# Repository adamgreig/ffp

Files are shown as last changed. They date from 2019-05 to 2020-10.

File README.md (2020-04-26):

# FFP: Flash/FPGA Programmer

FFP is a dead-simple USB to bidirectional SPI bridge for programming iCE40
FPGAs and SPI flashes. The hardware is an STM32F042 and not much else.
Firmware and host software is written in Rust.

The firmware additionally supports SWD via the CMSIS-DAP v1 and v2 protocols,
so many debuggers such as [probe-rs], [OpenOCD], and [pyOCD] are able to
use an FFP to debug and program Cortex-M and other microcontrollers.

[probe-rs]: https://probe.rs
[OpenOCD]: http://openocd.org
[pyOCD]: https://github.com/mbedmicro/pyOCD

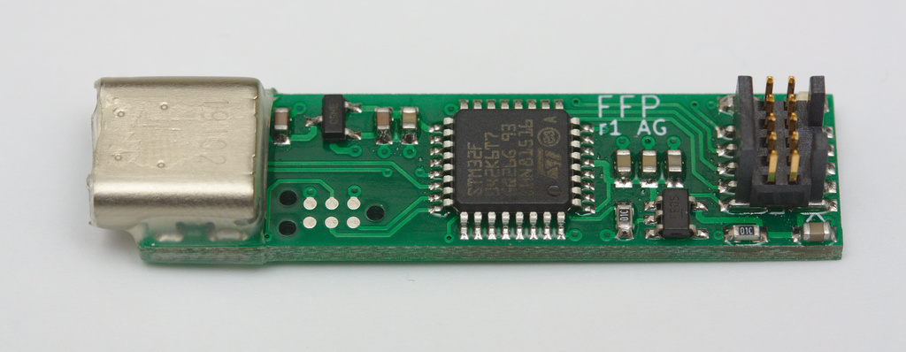
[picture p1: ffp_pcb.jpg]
Photo of FFP PCB


See [software/](software/) for the host-side software, [firmware/](firmware/)
for the embedded device firmware, and [hardware/](hardware/ffp/) for the
hardware design files.

## Pinout

The FFP r1 hardware uses a 5x2 pin 0.05"-pitch connector, which is also
commonly used for Cortex family microcontrollers for SWD and JTAG. The pinout
is deliberately compatible (though note `RESET` is moved) to allow hardware
reuse and for compatibility with tools such as TagConnect cables.

```ascii
          ______
    3v3 --|1  2|-- FLASH DI / FPGA DO / SWDIO
    GND --|3  4|-- CLK / SWCLK
    GND --|5  6|-- CS / SWO
        x-|7  8|-- FPGA nRST
    GND --|9 10|-- FLASH DO / FPGA DI / nRESET
          ------

```

This is the same pinout used by
[amp_flashprog](https://github.com/adamgreig/amp_flashprog), a custom firmware
for [Black Magic Probes](https://github.com/blacksphere/blackmagic) to bitbang
SPI to the same ends.

## Licence

Software and firmware is licensed under either of

* Apache License, Version 2.0 ([LICENSE-APACHE](LICENSE-APACHE) or
  http://www.apache.org/licenses/LICENSE-2.0)
* MIT license ([LICENSE-MIT](LICENSE-MIT) or http://opensource.org/licenses/MIT)

at your option.

Hardware design files are licensed under the Creative Commons Attribution
license ([CC-BY](https://creativecommons.org/licenses/by/4.0/)).

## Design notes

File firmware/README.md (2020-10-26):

# FFP Firmware

## Pre-built Binaries

Pre-built binaries are available for each release on the [Releases] page. See
below for instructions on using the files to program an FFP device. The easiest
method is to use `dfu-util` with the `ffp_firmware.dfu` pre-built file, which
uses the onboard USB bootloader.

[Releases]: https://github.com/adamgreig/ffp/releases

## Build Requirements

* You must have a working Rust compiler installed. Visit
[rustup.rs](https://rustup.rs) to install Rust.

* Your Rust toolchain needs the `thumbv6m-none-eabi` target installed:

```
rustup target add thumbv6m-none-eabi
```

## Building

Once Rust is installed, use Cargo to build:

```
cargo build --release
```

The resulting binary is an ELF file in
`target/thumbv6m-none-eabi/release/ffp_firmware` which can be programmed via
your usual programmer, or see below for generating a raw binary file and
bootloading over USB.

## Bootloading

You can reprogram the FFP using its built-in USB bootloader. You can use
[dfu-util](http://dfu-util.sourceforge.net/) or
[STM32CubeProg](https://www.st.com/en/development-tools/stm32cubeprog.html)
to perform the bootloading, both of which are available for Linux, MacOS, and
Windows.

To generate a binary file suitable for bootloading with dfu-util:
```
cargo build --release
arm-none-eabi-objcopy -O binary -S target/thumbv6m-none-eabi/release/ffp_firmware ffp.bin
dfu-suffix -a ffp.bin -v 0483 -p df11
```

STM32CubeProg can load data directly from the ELF file, but only if it has a
`.elf` extension. Simply copy the elf file:

```
cargo build --release
cp target/thumbv6m-none-eabi/release/ffp_firmware ffp_firmware.elf
```

To put an already-programmed FFP device into bootload mode:
```
ffp bootload
# or (if you do not have the ffp softare installed)
dfu-util -e
```
Devices which have a totally erased flash will come up in bootloader mode
automatically.

To bootload using dfu-util:
```
dfu-util -a 0 -s 0x08000000 -D ffp.bin
```

To bootload using STM32CubeProg, open the `ffp_firmware.elf` file made above,
and download it to the FFP.

Reconnect the device after programming to load new firmware.

### Preparing a DfuSe file

Using `dfu-tool`, a DfuSe file can be created for more convenient bootloading:

```
arm-none-eabi-objcopy -O binary -S target/thumbv6m-none-eabi/release/ffp_firmware ffp.bin
dfu-tool convert dfuse ffp.bin ffp.dfu
dfu-tool set-vendor ffp.dfu 0483
dfu-tool set-product ffp.dfu df11
dfu-tool set-address ffp.dfu 0x08000000
```

Unfortunately dfu-tool seemingly cannot set the alt setting to 0, only to >=1,
so that must still be specified by dfu-util:

```
dfu-util -a 0 -D ffp.dfu
```

## Licence

Licensed under either of

* Apache License, Version 2.0 ([LICENSE-APACHE](../LICENSE-APACHE)
  or http://www.apache.org/licenses/LICENSE-2.0 )
* MIT license ([LICENSE-MIT](../LICENSE-MIT) or
  http://opensource.org/licenses/MIT )

at your option.

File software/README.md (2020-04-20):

# FFP Control Software

The control software for FFP runs on your computer and uses the FFP hardware to
program an FPGA or SPI flash. It is written in Rust.

## Pre-built Binaries

Pre-built binaries are available for Windows and Linux on the [Releases] page.
You must have [libusb] installed or available on your system.

[Releases]: https://github.com/adamgreig/ffp/releases
[libusb]: https://libusb.info

## Build Requirements

* You must have a working Rust compiler installed. Visit
[rustup.rs](https://rustup.rs) to install Rust.

* You'll need to set up drivers or permissions to access the USB device, see
  the [drivers page](/driver/) for more details.

## Building

```
cargo build --release
```

You can either run the ffp executable directly from `target/release/ffp`, or
install it for your user using `cargo install --path .`.

## Installing

FFP software can be installed directly using Cargo:

```
cargo install ffp
```

## Usage

Run `ffp help` for detailed usage. Commonly used commands:

* `ffp fpga program bitstream.bin`
* `ffp fpga reset`
* `ffp fpga power on`
* `ffp flash id`
* `ffp flash program bitstream.bin`

## Python Alternative

The prototype for this software was written as a Python script which is also
available ([prog.py](/scripts/prog.py)).

## Cross-Compiling for Windows from Linux

From a stock Ubuntu 18.04 image, the following commands generate an `ffp.exe`
suitable for 64-bit Windows:

```sh
$ curl --proto '=https' --tlsv1.2 -sSf https://sh.rustup.rs | sh
# (accept defaults)
$ source $HOME/.cargo/env
$ cd /tmp
$ rustup target add x86_64-pc-windows-gnu
$ apt install -y p7zip-full build-essential gcc-mingw-w64-x86-64 libusb-1.0 pkg-config
$ wget https://github.com/libusb/libusb/releases/download/v1.0.23/libusb-1.0.23.7z
$ 7z x libusb-1.0.23.7z
$ git clone https://github.com/adamgreig/ffp
$ cd ffp/software
$ mkdir .cargo
$ echo -e '[target.x86_64-pc-windows-gnu]\nlinker = "x86_64-w64-mingw32-gcc"\nrustflags = [ "-L", "/tmp/MinGW64/dll/"]' > .cargo/config
$ env PKG_CONFIG_ALLOW_CROSS=1 cargo build --release --target x86_64-pc-windows-gnu
```

The resulting binary is `target/x86_64-pc-windows-gnu/release/ffp.exe`. It
needs the `libusb-1.0.dll` file from `/tmp/MinGW64/dll/` available on the
Windows system, either in the same directory as `ffp.exe` or installed
system-wide.

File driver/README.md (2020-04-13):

# FFP Platform-Specific Drivers

## Linux

Copy the `99-ffp.rules` file to your udev configuration directory and restart
udev:

```
sudo cp 99-ffp.rules /etc/udev/rules.d
sudo udevadm control --reload
```

Confirm you are in the `plugdev` group, or modify `99-ffp.rules` to use another
group or specify a specific user. If you have just added yourself to the
`plugdev` group (e.g., `sudo usermod -aG plugdev $USER`), you will need to
log out and log back in again for the group change to take effect.

## Windows

For use as an CMSIS-DAP v1 programmer, no additional driver installation should
be necessary, as the default HID drivers should work. However, this has not
been tested -- please report back if you've got the CMSIS-DAP functionality
working under Windows.

On Windows 8 and above, WinUSB drivers should automatically be installed for
FFP's SPI and CMSIS-DAP v2 interfaces. If these do not work, we recommend using
[Zadig](https://zadig.akeo.ie/) to set up a driver.  Download and run the Zadig
executable, select `FFP SPI Interface (Interface 0)` in the dropdown, and click
`Install Driver`, and click the `Replace Driver` button.  This will install a
default WinUSB driver for the FFP VID:PID combination on Interface 0, allowing
the FFP host software to use the device.

## MacOS

No information for MacOS is known at present. If you've got FFP working on
MacOS, please consider updating this file.

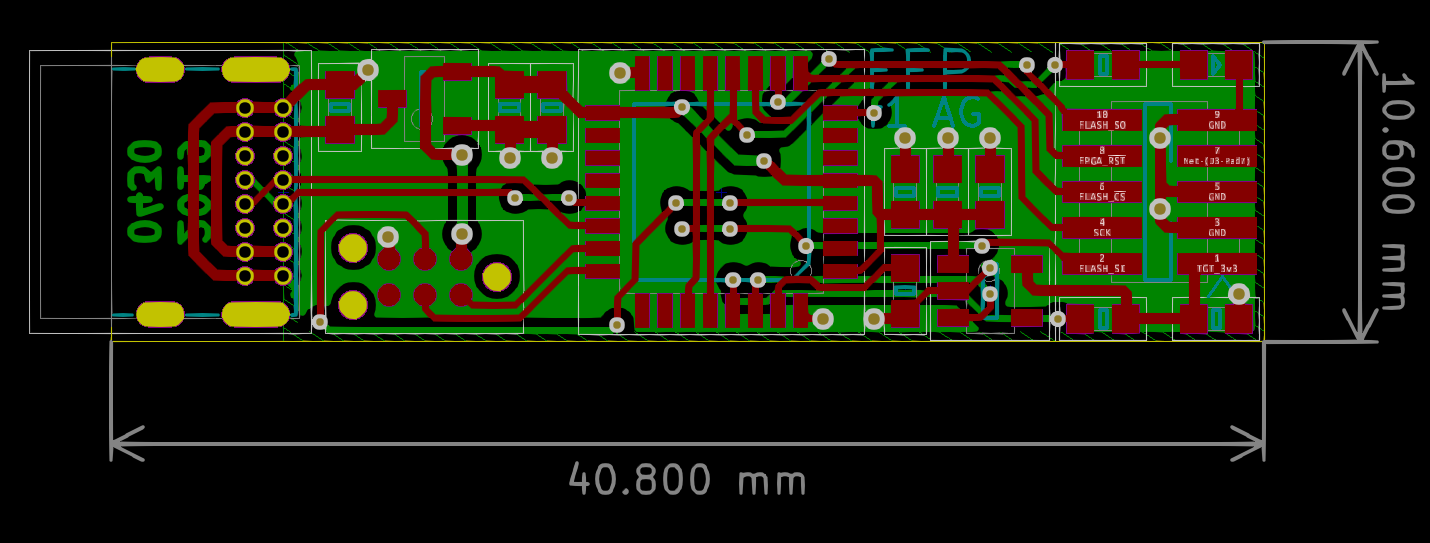
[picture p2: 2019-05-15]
hardware/ffp/ffp_pcb.png

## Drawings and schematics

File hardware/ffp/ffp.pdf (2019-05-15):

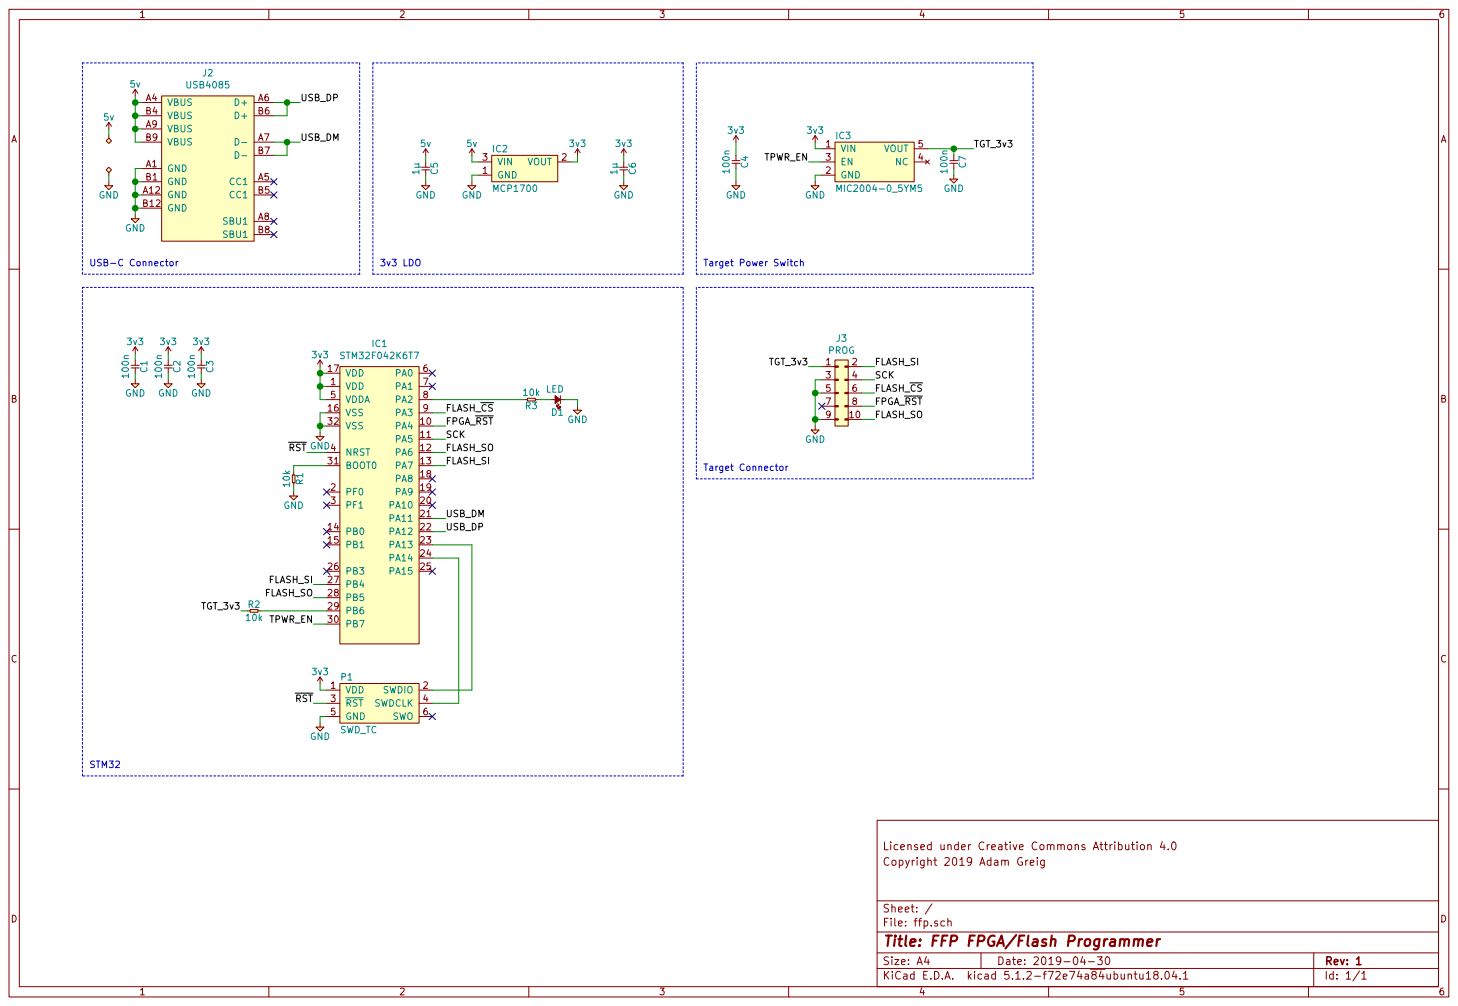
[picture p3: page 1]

Licensed under Creative Commons Attribution 4.0
File: ffp.sch Sheet: / Copyright 2019 Adam Greig

Id: 1/1 Title: FFP FPGA/Flash Programmer

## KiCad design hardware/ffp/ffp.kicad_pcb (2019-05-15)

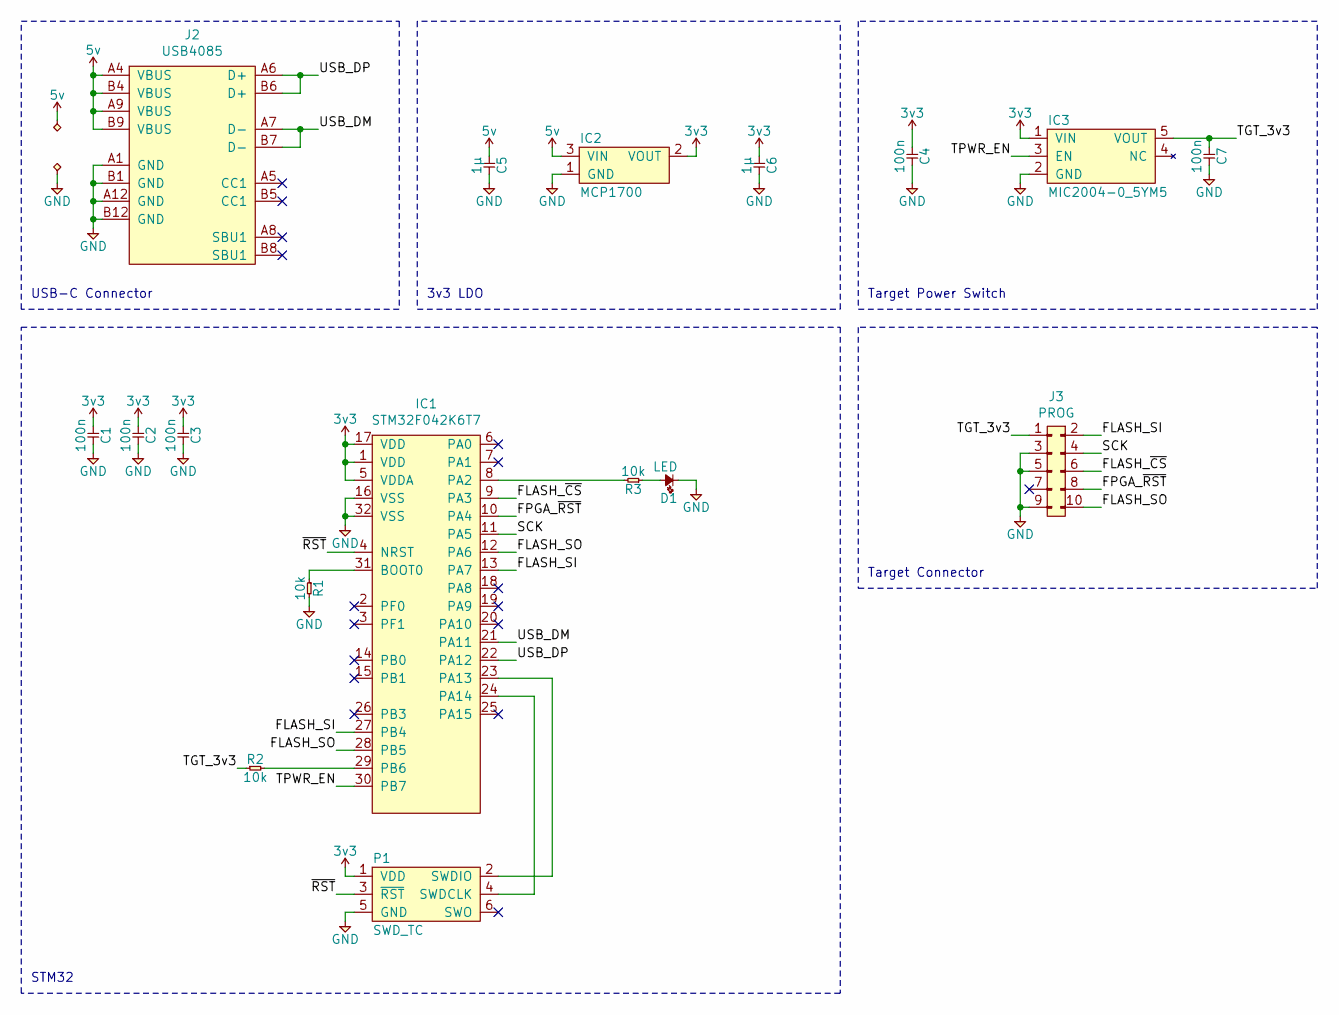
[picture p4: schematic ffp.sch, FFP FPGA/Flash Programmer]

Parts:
C1, C2, C3, C4, C7: 100n; 0603; Farnell 1759122
C5, C6: 1µ; 0603; Farnell 2768389
D1: LED; 0603-LED; Farnell 2610409
IC1: STM32F042K6T7; LQFP-32; Farnell 2469553
IC2: MCP1700; SOT-23; Farnell 1296592
IC3: MIC2004-0_5YM5; SOT-23-5; Farnell 2509877
J2: USB4085; Farnell 2924867
J3: PROG; FTSH-105-01-L-DV-K; Farnell 2856437
P1: SWD_TC; TC2030-NL
R1, R2, R3: 10k; 0603; Farnell 2447230

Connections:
3v3: C1.1, C2.1, C3.1, C4.1, C6.1, IC1.1 (VDD), IC1.5 (VDDA), IC1.17 (VDD), IC2.2 (VOUT), IC3.1 (VIN), P1.1 (VDD)
5v: C5.1, IC2.3 (VIN), J2.A4 (VBUS), J2.A9 (VBUS), J2.B4 (VBUS), J2.B9 (VBUS)
/FLASH_SI: IC1.13 (PA7), IC1.27 (PB4), J3.2
/FLASH_SO: IC1.12 (PA6), IC1.28 (PB5), J3.10
/FLASH_~CS: IC1.9 (PA3), J3.6
/FPGA_~RST: IC1.10 (PA4), J3.8
/SCK: IC1.11 (PA5), J3.4
/TGT_3v3: C7.1, IC3.5 (VOUT), J3.1, R2.1
/TPWR_EN: IC1.30 (PB7), IC3.3 (EN)
/USB_DM: IC1.21 (PA11), J2.A7 (D-), J2.B7 (D-)
/USB_DP: IC1.22 (PA12), J2.A6 (D+), J2.B6 (D+)
/~RST: IC1.4 (NRST), P1.3 (~RST)
GND: C1.2, C2.2, C3.2, C4.2, C5.2, C6.2, C7.2, D1.1, IC1.16 (VSS), IC1.32 (VSS), IC2.1 (GND), IC3.2 (GND), J2.A1 (GND), J2.A12 (GND), J2.B1 (GND), J2.B12 (GND), J3.3, J3.5, J3.9, P1.5 (GND), R1.2
unnamed: D1.2, R3.1
unnamed: IC1.8 (PA2), R3.2
unnamed: IC1.23 (PA13), P1.2 (SWDIO)
unnamed: IC1.24 (PA14), P1.4 (SWDCLK)
unnamed: IC1.29 (PB6), R2.2
unnamed: IC1.31 (BOOT0), R1.1

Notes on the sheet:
USB-C Connector
3v3 LDO
Target Power Switch
Target Connector
STM32

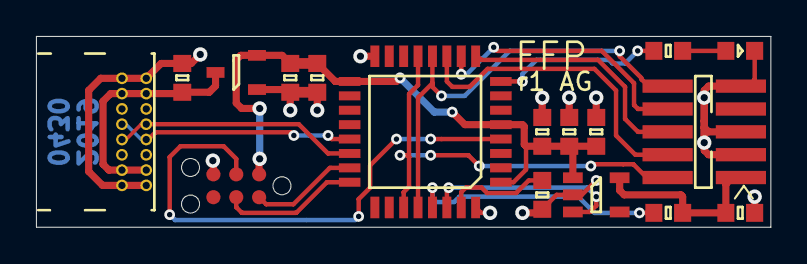
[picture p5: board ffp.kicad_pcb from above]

Board: 2 copper layers, 40.8 x 10.6 mm, 17 parts (0 on the bottom side), 19 nets.

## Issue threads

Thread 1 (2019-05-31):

Question regarding port to STM32F070

anuejn, 2019-05-31:
Hi adamgreig,
first, thanks for your great effort in building rust code for embedded.

We are trying to port the firmware part of this project to [another board](https://github.com/icerink/iceskate), which uses a slightly different microcontroller (STM32F070F6P6) without the USB clock recovery feature. Because of this we are using an external crystal oscillator and the internal pll to generate the 48Mhz for the USB peripheral (see [this diff](https://github.com/icerink/ffp/commit/4e44447b065a5f8184fce2633d88c65f898f41ad)).

The dfu bootloader from ST is working fine on the board, so the hardware seems to be working.

However, the device is not enumerating properly and it seems like the USB stack is not responding. The error we get is:
```
[11859.787068] usb 2-3: new full-speed USB device number 17 using xhci_hcd
[11859.937106] usb 2-3: device descriptor read/64, error -71
[11860.207122] usb 2-3: device descriptor read/64, error -71
[11860.477049] usb 2-3: new full-speed USB device number 18 using xhci_hcd
[11860.627086] usb 2-3: device descriptor read/64, error -71
[11860.897080] usb 2-3: device descriptor read/64, error -71
[11861.017107] usb usb2-port3: attempt power cycle
[11861.727065] usb 2-3: new full-speed USB device number 19 using xhci_hcd
[11861.727242] usb 2-3: Device not responding to setup address.
[11861.947235] usb 2-3: Device not responding to setup address.
[11862.177017] usb 2-3: device not accepting address 19, error -71
[11862.327057] usb 2-3: new full-speed USB device number 20 using xhci_hcd
[11862.327091] usb 2-3: Device not responding to setup address.
[11862.547132] usb 2-3: Device not responding to setup address.
[11862.767028] usb 2-3: device not accepting address 20, error -71
[11862.767067] usb usb2-port3: unable to enumerate USB device
```

We suspect that we miss something in the powerup / clock setup sequence, since we get similiar errors if we set a wrong pll multiplier in a firmware generated by `STM32Cube`. Do you have any ideas / hints?

adamgreig, 2019-05-31:
Looks like a cool project! It definitely seems like the USB peripheral is
not running at the correct frequency and that's why it's not enumerating.
You might try enabling one of the clock outputs or a timer to see if you
can measure the actual frequency.

I'm away on a work trip at the moment but will try and find some time to
check your diff in the next couple of days. Looks fine at a first glance
though.

adamgreig, 2020-04-08:
I'm closing this issue now as it's pretty old but feel free to re-open or open a new issue if you want to keep discussing!

Closed 2020-04-08.

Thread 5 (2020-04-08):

DAP: Support reading SWO

adamgreig, 2020-04-08:
Currently there's no SWO support. It requires bringing up the UART on the SWO pin, setting that up to read into a buffer, and responding to the [SWO commands](https://arm-software.github.io/CMSIS_5/DAP/html/group__DAP__swo__gr.html). Probably a bit of work but could be quite useful. ~~For now I anticipate only implementing SWO over the HID endpoint, though in future we could use the CMSIS-DAP v2 SWO streaming endpoint for higher throughput.~~ Since CMSIS-DAP v2 is working well, it seems obvious to get SWO working over that too.

Closed 2020-04-26.

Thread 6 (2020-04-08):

DAP: Support WinUSB

adamgreig, 2020-04-08:
CMSIS-DAP v2 adds [WinUSB](https://arm-software.github.io/CMSIS_5/DAP/html/group__DAP__ConfigUSB__gr.html) support, which would be a lot faster than the current HID-based protocol. The STM32F042 should have enough endpoints to implement this alongside HID and the SPI protocol, even including SWO streaming. Not sure how messy WinUSB actually is to implement - if it's just another descriptor and a bulk endpoint that streams the same commands as the HID endpoints, it might be pretty quick to do.

Closed 2020-04-14.

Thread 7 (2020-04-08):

FW: Support bootloading without manually setting fuse

adamgreig, 2020-04-08:
Currently jumping to bootloader only works if the BOOT_SEL fuse bit is set, otherwise the system bootloader immediately jumps to user code. There seem to be a few ways to work around this:

* Write the fuse from our own firmware if not set
* Drive the BOOT0 pin as GPIO immediately before rebooting?
* ...?

Closed 2020-04-11.

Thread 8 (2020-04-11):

Can not build firmware successful. and how to build ffp host software for windows?

Droid-MAX, 2020-04-11:
Compiling output below:

error[E0463]: can't find crate for `core`
  |
  = note: the `thumbv6m-none-eabi` target may not be installed

error: aborting due to previous error

For more information about this error, try `rustc --explain E0463`.
error: could not compile `stable_deref_trait`.

OS Type:
Linux 4.9.0 Debian 9

Rustc/Cargo Version:
rustc 1.44.0-nightly (94d346360 2020-04-09)
cargo 1.44.0-nightly (390e8f245 2020-04-07)

adamgreig, 2020-04-11:
It looks like you need the thumbv6m-none-eabi target added, try:

```
rustup target add thumbv6m-none-eabi
```

Thanks for reporting! I've updated the firmware README with more instructions so this should be easier for people in future, too.

adamgreig, 2020-04-11:
Let me know if that fixed it! For the host software, does `cargo build --release` work? You probably need libusb installed, but I'm afraid I don't know how to set that up on Windows.

Droid-MAX, 2020-04-11:
firmware build successful! but have no idea about how to set that up on windows too.

Droid-MAX, 2020-04-11:
I think the installation command of dfu-util package should also be written in README.md

Droid-MAX, 2020-04-12:
Can you help me test the cross-compiled ffp.exe?

https://github.com/Droid-MAX/ffp/releases/tag/1.2.0-beta

Related files are in this link.

adamgreig, 2020-04-12:
Sorry, I don't have access to any Windows systems so I can't test the EXEs myself. If you could write what is needed for Windows driver installation I'd like to add it to the `driver/README.md` file here though. I think instead of using zadig it should be possible to create a suitable WinUSB driver file specific for the FFP which works with libusb.

By the way, is there a reason your ffp repository is a whole separate repository instead of a fork? No problem, just interested.

adamgreig, 2020-04-12:
Ok, I was able to get this working in a VM. It actually needed a firmware fix*. I've made some driver files using zadig which I'll add to this repository. Your pre-built ffp.exe works fine:

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

I'll add some instructions to the README.

\* Windows requests a configuration descriptor with length 255 bytes, and the ffp descriptor total is 64 bytes, so a correct reply needs to send a zero-length packet after the 64 bytes. On Linux, the request is made for exactly 64 bytes, so the zero-length packet is not required, so I didn't notice this. It's fixed now.

adamgreig, 2020-04-13:
Hi @Droid-MAX, I've updated the software to use `rusb` instead of `libusb`, which seems to build on Windows without any other requirement or installation. Hopefully this makes Windows builds easier.

I've also changed the firmware to use WinUSB and Windows OS feature detection so I think zadig should not be needed either, the devices should automatically be recognised and use WinUSB drivers.

Droid-MAX, 2020-04-14:
It doesn't really matter, don't forget that dfu-util needs zadig in addition to ffp. I suggest keeping the status quo.

Droid-MAX, 2020-04-14:
after you updated software source code, It failed when I cross-compiled it and prompt miss "poll.h".

Droid-MAX, 2020-04-14:
latest firmware released:
https://github.com/Droid-MAX/ffp/releases/tag/1.2.0-beta-20200414

adamgreig, 2020-04-15:
> after you updated software source code, It failed when I cross-compiled it and prompt miss "poll.h" in mingw env.
> It is recommended to roll back to the previous version of the software.
> libusb1-sys does not consider the case of cross compilation.

Hmm, that's annoying. I swapped because `libusb` is 4 years old and not maintained, but `rusb` is a fork that is actively maintained. I believe `libusb1-sys` is also just an updated fork of `libusb-sys`, so they should cross-compile the same. I was able to build ffp.exe successfully on Windows 7 with MSVC using `rusb`, but I can't get either version to cross compile.

How did you cross compile the old version?

Droid-MAX, 2020-04-15:
Or you release the latest control software, pay attention to distinguish between 32-bit and 64-bit versions.

adamgreig, 2020-04-15:
Ok, I was able to cross-compile in the end. Here's the full instructions from a totally stock Ubuntu 18.04 image:

```sh
$ curl --proto '=https' --tlsv1.2 -sSf https://sh.rustup.rs | sh
# (accept defaults)
$ source $HOME/.cargo/env
$ cd /tmp
$ rustup target add x86_64-pc-windows-gnu
$ apt install -y p7zip-full build-essential gcc-mingw-w64-x86-64 libusb-1.0 pkg-config
$ wget https://github.com/libusb/libusb/releases/download/v1.0.23/libusb-1.0.23.7z
$ 7z x libusb-1.0.23.7z
$ git clone https://github.com/adamgreig/ffp
$ cd ffp/software
$ mkdir .cargo
$ echo -e '[target.x86_64-pc-windows-gnu]\nlinker = "x86_64-w64-mingw32-gcc"\nrustflags = [ "-L", "/tmp/MinGW64/dll/"]' > .cargo/config
$ env PKG_CONFIG_ALLOW_CROSS=1 cargo build --release --target x86_64-pc-windows-gnu
```

Resulting binary is `target/x86_64-pc-windows-gnu/release/ffp.exe`, and I tested it on a Windows 7 (x64) VM. It needs the `libusb-1.0.dll` file available on the Windows system, either in the same directory as `ffp.exe` or installed system-wide. I think this should work for 32-bit too if you change the relevant targets and use the 32-bit `libusb-1.0.dll`.

This is encouraging so I plan to set up automatic build of software for Windows and Linux via CI sometime, but I'm not sure when.

adamgreig, 2020-04-15:
I think that answers this issue, so I'll close this one now, but please respond if you have any questions or open new issues for any other problems.

Thank you for encouraging me to investigate Windows builds, I'm glad it can be done and now supports Windows!

I would be interested to know if the latest firmware still requires zadig WinUSB drivers installed on Windows, or if it just works out of the box now. As far as I can tell, I'm doing everything right for WinUSB drivers to activate.

Droid-MAX, 2020-04-15:
I also think that the CI system should be used to complete the compilation automatically.

adamgreig, 2020-04-20:
@Droid-MAX, CI now have pre-built windows executables and firmware images: https://github.com/adamgreig/ffp/releases/tag/v1.3.0

Closed 2020-04-15.

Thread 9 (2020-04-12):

No enumeration on Windows

adamgreig, 2020-04-12:
Our configuration descriptor is exactly 64 bytes, which is also the maximum packet size. If a setup transfer is requested from the host with length exactly 64 bytes, there's no problem since no final zero length packet (ZLP) is expected. This is the case on Linux, which reads 9 bytes to determine the full configuration length, then reads exactly 64 bytes.

However on Windows, _after_ reading the full configuration successfully once, a second read is made for 255 bytes. We respond with 64 bytes, don't send anything else, Windows waits 5s for the ZLP then gives up and fails to enumerate.

Closed 2020-04-12.

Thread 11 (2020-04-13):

DAP: JTAG Support

adamgreig, 2020-04-13:
Currently the firmware only supports the SWD protocol. Having JTAG support as well could be convenient, especially for use as an FPGA programmer with non-iCE40 devices such as ECP5 which have JTAG ports.

I'm not sure how the hardware support will work out for JTAG; parts or all of it may require bitbanging as only one SPI device is available.

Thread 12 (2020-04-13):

SW: Swap from libusb to rusb

adamgreig, 2020-04-13:
Currently FFP software uses [libusb](https://crates.io/crates/libusb), which hasn't been updated in years. We should look to swap to [rusb](https://crates.io/crates/rusb) which is more recently updated, and might make building simpler as it fetches libusb source code automatically.

Closed 2020-04-13.

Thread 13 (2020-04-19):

DAP: Investigate supporting multiple queued commands

adamgreig, 2020-04-19:
CMSIS-DAP's DAP_Info command returns a 'maximum packet count', which reflects how many packets the probe can have on-the-go at once. As far as I can tell, this refers to an internal queue of incoming requests which are processed in-order and then results returned in-order in an outgoing queue. Currently the firmware returns '1' for this field, and we always send the result of a request before receiving the next one.

However, this limits USB throughput, especially in HID mode where each frame will either be a new command or a response, but not both. If we could implement a short queue it might help improve throughput. The `DAP_TransferAbort` command might make more sense too.

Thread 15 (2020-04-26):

DAP: Detect SWO buffer overflow

adamgreig, 2020-04-26:
Currently SWO buffer overflows are not detectable, as the read method has no way to distinguish how many times the DMA index might have wrapped around compared to the last read position. It might be possible to use the DMA half/full transfer complete flags in some fashion to detect overflow. Alternatively it might be possible to use the UART RXNE interrupt pending bit to poll for that in the application loop, but it seems higher overhead and messier.

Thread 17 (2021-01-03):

Swap to spi-flash library

adamgreig, 2021-01-03:
[spi-flash](https://github.com/adamgreig/spi-flash-rs) has more extensive support for reading parameters and working out the best way to erase/write flash, and should be basically a drop-in replacement for `flash.rs`.

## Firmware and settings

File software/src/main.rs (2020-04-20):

use std::fs::File;
use std::io::prelude::*;
use std::time::Instant;
use clap::{Arg, App, AppSettings, SubCommand};
use clap::{value_t, crate_authors, crate_description, crate_version};
use ffp::{Programmer, Flash, FPGA};

#[allow(clippy::cognitive_complexity)]
fn main() -> ffp::Result<()> {
    let matches = App::new("ffp fpga/flash programmer")
        .version(crate_version!())
        .author(crate_authors!())
        .about(crate_description!())
        .setting(AppSettings::SubcommandRequiredElseHelp)
        .global_setting(AppSettings::ColoredHelp)
        .global_setting(AppSettings::DeriveDisplayOrder)
        .global_setting(AppSettings::GlobalVersion)
        .global_setting(AppSettings::InferSubcommands)
        .global_setting(AppSettings::VersionlessSubcommands)
        .arg(Arg::with_name("quiet")
             .help("Suppress informative output")
             .long("quiet")
             .short("q")
             .global(true))
        .arg(Arg::with_name("serial")
             .help("Serial number of FFP device to use")
             .long("serial")
             .short("s")
             .takes_value(true)
             .global(true))
        .arg(Arg::with_name("index")
             .help("Index of FFP device to use")
             .long("index")
             .short("i")
             .conflicts_with("serial")
             .takes_value(true)
             .global(true))
        .subcommand(SubCommand::with_name("fpga")
            .about("Reset, power, and program the FPGA")
            .setting(AppSettings::SubcommandRequiredElseHelp)
            .subcommand(SubCommand::with_name("reset")
                        .about("Reset the FPGA"))
            .subcommand(SubCommand::with_name("power")
                        .about("Control FPGA power from FFP board")
                        .arg(Arg::with_name("power")
                             .possible_values(&["on", "off"])
                             .required(true)))
            .subcommand(SubCommand::with_name("program")
                        .about("Program FPGA with bitstream")
                        .arg(Arg::with_name("file")
                             .help("File to program to FPGA")
                             .required(true))))
        .subcommand(SubCommand::with_name("flash")
            .about("Read/write flash memory")
            .setting(AppSettings::SubcommandRequiredElseHelp)
            .subcommand(SubCommand::with_name("id")
                        .about("Read flash ID"))
            .subcommand(SubCommand::with_name("erase")
                        .about("Completely erase flash"))
            .subcommand(SubCommand::with_name("program")
                        .about("Program flash chip with binary data from file")
                        .arg(Arg::with_name("file")
                             .help("File to write to flash")
                             .required(true))
                        .arg(Arg::with_name("offset")
                             .help("Start address (in bytes) to read from")
                             .long("offset")
                             .default_value("0"))
                        .arg(Arg::with_name("no-verify")
                             .help("Disable automatic readback verification")
                             .short("n")
                             .long("no-verify")))
            .subcommand(SubCommand::with_name("read")
                        .about("Read contents of flash chip to file")
                        .arg(Arg::with_name("file")
                             .help("File to write with contents of flash")
                             .required(true))
                        .arg(Arg::with_name("length")
                             .help("Length (in bytes) to read from flash")
                             .long("length")
                             .default_value("135183"))
                        .arg(Arg::with_name("offset")
                             .help("Start address (in bytes) to read from")
                             .long("offset")
                             .default_value("0"))))
        .subcommand(SubCommand::with_name("bootload")
            .about("Reset FFP hardware into USB bootloader"))
        .subcommand(SubCommand::with_name("devices")
            .about("List available FFP devices"))
        .get_matches();

    let t0 = Instant::now();
    let context = rusb::Context::new().expect("Error getting rusb context");
    let quiet = matches.is_present("quiet");

    // Special-case devices which does not need a programmer
    if matches.subcommand_name().unwrap() == "devices" {
        let devices = Programmer::get_serials(&context)?;
        match devices.len() {
            0 => println!("No FFP devices found."),
            _ => {
                match devices.len() {
                    1 => println!("1 device found:"),
                    _ => println!("{} devices found:", devices.len()),
                }
                for (idx, serial) in devices.iter().enumerate() {
                    println!("    {}: {}", idx, serial);
                }
            },
        }
        return Ok(());
    }

    let programmer = if matches.is_present("serial") {
        Programmer::by_serial(&context, matches.value_of("serial").unwrap())
    } else if matches.is_present("index") {
        Programmer::by_index(&context, value_t!(matches.value_of("index"), usize).unwrap())
    } else {
        Programmer::find(&context)
    }?;

    match matches.subcommand_name() {
        Some("fpga") => {
            let fpga = FPGA::new(&programmer);
            let matches = matches.subcommand_matches("fpga").unwrap();
            match matches.subcommand_name() {
                Some("reset") => {
                    if !quiet { println!("Resetting FPGA") };
                    fpga.reset()?;
                },
                Some("power") => {
                    let matches = matches.subcommand_matches("power").unwrap();
                    let arg = matches.value_of("power").unwrap();
                    if arg == "on" {
                        if !quiet { println!("Turning on target power") };
                        fpga.power_on()?;
                    } else if arg == "off" {
                        if !quiet { println!("Turning off target power") };
                        fpga.power_off()?;
                    }
                },
                Some("program") => {
                    if !quiet { println!("Programming FPGA") };
                    let matches = matches.subcommand_matches("program").unwrap();
                    let path = matches.value_of("file").unwrap();
                    let mut file = File::open(path)?;
                    let mut data = Vec::new();
                    file.read_to_end(&mut data)?;
                    fpga.program(&data)?;
                },
                _ => panic!(),
            }
        },
        Some("flash") => {
            let flash = Flash::new(&programmer);
            let id = flash.read_id().expect("Error reading flash ID");
            if !quiet { println!("Flash ID: {}", id) };
            let matches = matches.subcommand_matches("flash").unwrap();
            match matches.subcommand_name() {
                Some("id") => {
                    if quiet { println!("Flash ID: {}", id) };
                },
                Some("erase") => {
                    if !quiet { println!("Erasing flash") };
                    flash.erase()?;
                },
                Some("program") => {
                    if !quiet { println!("Programming flash") };
                    let matches = matches.subcommand_matches("program").unwrap();
                    let path = matches.value_of("file").unwrap();
                    let offset = value_t!(matches.value_of("offset"), u32).unwrap();
                    let verify = !matches.is_present("no-verify");
                    let mut file = File::open(path)?;
                    let mut data = Vec::new();
                    file.read_to_end(&mut data)?;
                    flash.program(offset, &data, verify)?;
                    programmer.unreset()?;
                },
                Some("read") => {
                    if !quiet { println!("Reading flash to file") };
                    let matches = matches.subcommand_matches("read").unwrap();
                    let path = matches.value_of("file").unwrap();
                    let offset = value_t!(matches.value_of("offset"), u32).unwrap();
                    let length = value_t!(matches.value_of("length"), usize).unwrap();
                    let mut file = File::create(path)?;
                    let data = flash.read(offset, length)?;
                    file.write_all(&data)?;
                },
                _ => panic!(),
            }
        },
        Some("bootload") => {
            if !quiet { println!("Resetting FFP into bootloader") };
            programmer.bootload()?;
        },
        _ => panic!(),
    };

    let t1 = t0.elapsed();
    if !quiet { println!("Finished in {}.{:02}s", t1.as_secs(), t1.subsec_millis()/10) };

    Ok(())
}

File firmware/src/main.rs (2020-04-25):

// Copyright 2019 Adam Greig
// Dual licensed under the Apache 2.0 and MIT licenses.

#![no_std]
#![no_main]

extern crate panic_halt;
use cortex_m_rt::{entry, pre_init};
use git_version::git_version;

const GIT_VERSION: &str = git_version!();

pub mod hal;
pub mod app;
pub mod swd;
pub mod dap;

#[pre_init]
unsafe fn pre_init() {
    // Check if we should jump to system bootloader.
    //
    // When we receive the BOOTLOAD command over USB,
    // we write a flag to a static and reset the chip,
    // and `bootload::check()` will jump to the system
    // memory bootloader if the flag is present.
    //
    // It must be called from pre_init as otherwise the
    // flag is overwritten when statics are initialised.
    hal::bootload::check();
}

#[entry]
fn main() -> ! {
    let flash = hal::flash::Flash::new(stm32ral::flash::Flash::take().unwrap());
    let rcc = hal::rcc::RCC::new(stm32ral::rcc::RCC::take().unwrap(),
                                 stm32ral::crs::CRS::take().unwrap());
    let nvic = hal::nvic::NVIC::new(stm32ral::nvic::NVIC::take().unwrap(),
                                    stm32ral::scb::SCB::take().unwrap());
    let dma = hal::dma::DMA::new(stm32ral::dma1::DMA1::take().unwrap());
    let gpioa = hal::gpio::GPIO::new(stm32ral::gpio::GPIOA::take().unwrap());
    let gpiob = hal::gpio::GPIO::new(stm32ral::gpio::GPIOB::take().unwrap());
    let spi = hal::spi::SPI::new(stm32ral::spi::SPI1::take().unwrap());
    let mut uart = hal::uart::UART::new(stm32ral::usart::USART2::take().unwrap(), &dma);
    let mut usb = hal::usb::USB::new(stm32ral::usb::USB::take().unwrap());

    // Define pinout.
    // Some pins are defined early so we can memoise their modes for
    // faster mode switching at runtime.
    let sck = gpioa.pin(5);
    let flash_si = gpioa.pin(7);
    let flash_si_input_mode = flash_si.memoise_mode_input();
    let flash_si_alternate_mode = flash_si.memoise_mode_alternate();
    let sck_output_mode = sck.memoise_mode_output();
    let sck_alternate_mode = sck.memoise_mode_alternate();
    let pins = hal::gpio::Pins {
        led: gpioa.pin(2),
        cs: gpioa.pin(3),
        fpga_rst: gpioa.pin(4),
        sck,
        flash_so: gpioa.pin(6),
        flash_si,
        fpga_so: gpiob.pin(4),
        fpga_si: gpiob.pin(5),
        tpwr_det: gpiob.pin(6),
        tpwr_en: gpiob.pin(7),

        flash_si_input_mode,
        flash_si_alternate_mode,
        sck_output_mode,
        sck_alternate_mode,
    };

    let swd = swd::SWD::new(&spi, &pins);
    let mut dap = dap::DAP::new(swd, &mut uart, &pins);

    // Create App instance with the HAL instances
    let mut app = app::App::new(
        &flash, &rcc, &nvic, &dma, &pins, &spi, &mut usb, &mut dap);

    // Initialise application, including system peripherals
    app.setup();

    loop {
        // Process events
        app.poll();
    }
}

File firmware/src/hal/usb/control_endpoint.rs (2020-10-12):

// Copyright 2019-2020 Adam Greig
// Dual licensed under the Apache 2.0 and MIT licenses.

use core::convert::TryFrom;

use stm32ral::usb;
use stm32ral::{read_reg, write_reg};

use super::{USBStackRequest, Endpoint, stat_stall, stat_nak, stat_valid};
use super::packets::{*, ToBytes};
use super::buffers::*;
use super::descriptors::*;

use crate::app::{PinState, Mode, Request};
use crate::hal::unique_id::get_hex_id;

/// USB handling code for control endpoint
pub(super) struct ControlEndpoint {
    epbuf: &'static mut EPBuf,
    btable: &'static mut BTableRow,
    pending_request: Option<USBStackRequest>,
    pending_tx: Option<(usize, usize)>,
    pending_tx_buf: [u8; 256],
}

impl ControlEndpoint {

    /// Handle transmission completion.
    ///
    /// Either we still have more data to transmit, in which case we prepare
    /// remaining data for transmission, or we have finished transmitting
    /// an acknowledgement and can now process an incoming request.
    fn process_tx_complete(&mut self, usb: &usb::Instance) -> Option<USBStackRequest> {
        // If we have more data to transmit, enqueue it
        if self.pending_tx.is_some() {
            self.transmit_next(usb);
        }

        // For many requests, especially including SET_ADDRESS, SET_CONFIGURATION,
        // or bootload, we have to ensure the response ACK has been transmitted
        // before the request is processed. The ControlEndpoint stores the request
        // and releases it to the stack after the ACK is sent.
        core::mem::take(&mut self.pending_request)
    }

    /// Handle reception completion.
    ///
    /// This typically fires after receiving a SETUP packet containing a request.
    fn process_rx_complete(&mut self, usb: &usb::Instance) -> Option<USBStackRequest> {
        let stack_request = if read_reg!(usb, usb, EP0R, SETUP) == 1 {
            self.process_setup(usb)
        } else {
            None
        };

        // Resume reception on EP0
        self.rx_valid(usb);

        stack_request
    }

    /// Process receiving a SETUP packet.
    ///
    /// This may be a StandardRequest from the USB spec, or a vendor-specific
    /// request for our own application.
    fn process_setup(&mut self, usb: &usb::Instance) -> Option<USBStackRequest> {
        let setup = SetupPID::from_buf(&self.epbuf);
        match setup.setup_type() {
            // Process standard requests
            SetupType::Standard => match StandardRequest::try_from(setup.bRequest) {
                Ok(StandardRequest::GetDescriptor) => {
                    let [descriptor_index, descriptor_type] = setup.wValue.to_le_bytes();
                    self.process_get_descriptor(
                        usb, setup.wLength, descriptor_type as u8, descriptor_index as u8);
                    None
                },
                Ok(StandardRequest::GetStatus) => {
                    // Reply with dummy status 0x0000
                    let data = [0u8, 0u8];
                    self.transmit_slice(usb, &data[..]);
                    None
                },
                Ok(StandardRequest::SetAddress) => {
                    // Store new address to apply after ACK is sent
                    self.pending_request = Some(USBStackRequest::SetAddress(setup.wValue));
                    self.transmit_ack(usb);
                    None
                },
                Ok(StandardRequest::SetConfiguration) => {
                    // Apply requested configuration after ACK is sent
                    self.pending_request = match setup.wValue {
                        0 => Some(USBStackRequest::Reset),
                        1 => Some(USBStackRequest::SetConfiguration),
                        _ => None,
                    };
                    self.transmit_ack(usb);
                    None
                },
                _ => {
                    // Reject unknown requests
                    self.stall(usb);
                    None
                },
            },

            // Process class-specific requests
            SetupType::Class => self.process_class_request(usb, &setup),

            // Process vendor-specific requests
            SetupType::Vendor => self.process_vendor_request(usb, &setup),

            // Ignore unknown request types
            _ => { self.stall(usb); None },
        }
    }

    /// Send a 0-length ACK STATUS response to the next IN transfer
    fn transmit_ack(&mut self, usb: &usb::Instance) {
        self.btable.tx_count(0);
        self.tx_valid(usb);
    }

    fn transmit_next(&mut self, usb: &usb::Instance) {
        if let Some((idx, len)) = self.pending_tx {
            if len < 64 {
                // When there's less than the maximum packet size remaining,
                // immediately send all remaining data.
                // This also includes the case where len==0 and we send a ZLP.
                self.epbuf.write_tx(&self.pending_tx_buf[idx..idx+len]);
                self.btable.tx_count(len);
                self.pending_tx = None;
            } else {
                // For 64 or more bytes remaining, transmit next packet
                // and adjust pending_tx.
                self.epbuf.write_tx(&self.pending_tx_buf[idx..idx+64]);
                self.btable.tx_count(64);
                self.pending_tx = Some((idx+64, len-64));
            }
            self.tx_valid(usb);
        }
    }

    /// Indicate a packet has been loaded into the buffer and is ready for transmission
    fn tx_valid(&mut self, usb: &usb::Instance) {
        let (stat_tx, ep_type, ea) = read_reg!(usb, usb, EP0R, STAT_TX, EP_TYPE, EA);
        write_reg!(usb, usb, EP0R, CTR_RX: 1, EP_TYPE: ep_type, CTR_TX: 1, EA: ea,
                   STAT_TX: stat_valid(stat_tx));
    }

    /// Set the control endpoint to STALL in both directions
    ///
    /// This indicates an error processing the request to the host,
    /// and will be reset by hardware to NAK on both directions upon
    /// the next SETUP reception.
    fn stall(&mut self, usb: &usb::Instance) {
        let (stat_tx, stat_rx, ep_type, ea) =
            read_reg!(usb, usb, EP0R, STAT_TX, STAT_RX, EP_TYPE, EA);
        write_reg!(usb, usb, EP0R, CTR_RX: 1, EP_TYPE: ep_type, CTR_TX: 1, EA: ea,
                   STAT_TX: stat_stall(stat_tx), STAT_RX: stat_stall(stat_rx));
    }
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

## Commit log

2019-04-30 r1 of ffp hardware
    [ffp-B_Cu.gbl, ffp-B_Mask.gbs, ffp-B_Paste.gbp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]
2019-05-01 Tidy schematic and render PDF
    [ffp.sch]
2019-05-05 Update datasheet for stm32f0
    [ffp.sch]
2019-05-07 Add photo of PCB
2019-05-08 Toggle LED based on SetCS request
2019-05-08 Swap to single main loop instead of interrupts
    This allows storing state inside the HAL drivers (since they no longer
    need to be able to be "stolen" by the ISRs), removes all `steal()`
    methods, and should simplify the rest of the application logic (dealing
    with events coming to/from the USB).
    We can use WFE and SEVONPEND to continue to sleep until an interrupt
    occurs. Increased response latency should be negligable so long as we
    don't start blocking in the main loop.
    [gpio.rs, main.rs, mod.rs]
2019-05-09 Remove LED handling from usb HAL
2019-05-12 Add basic SPI support with blocking DMA transfers
2019-05-15 Release under open-source licences
    [ffp.kicad_pcb, ffp.sch]
2019-05-15 Add updated schematic pdf and PCB png
2019-05-22 Swap to newly-assigned USB PID FF50
    [descriptors.rs, main.rs, prog.py]
2019-06-13 Add command line output and timer
2019-06-13 Update driver link in readme
2019-06-13 Set high-z mode on exit, along with turning off LED
2019-06-14 Report device unique ID as USB serial number
2019-06-14 Update ffp software to support multiple FFP devices
2020-04-03 memoise swd mode swaps to speed them up a bit
    [gpio.rs, main.rs, swd.rs]
2020-04-03 Fix RDATA parity and other tidyups
    [gpio.rs, main.rs, spi.rs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]
2020-04-03 Get HID report working, device is recongised as a CMSIS-DAP probe!
2020-04-03 Swap to num_enum instead of hand-written conversions
    [mod.rs]
2020-04-12 Re-implement sending control data longer than 64 bytes.
    This effectively reverts 1dee501d522e7fae2124533de5eafc2261450c89.
    We can now send up to 320 byte control responses, which allows for
    longer descriptors and strings, but crucially also causes us to send
    ZLPs after an exactly 64-byte transfer, fixing a failure to enumerate
    on Windows.
    Closes #9.
    [control_endpoint.rs]
2020-04-12 Update READMEs with more details on building and flashing firmware and software and on Windows drivers
2020-04-13 Swap from libusb to rusb crate. Closes #12
    [main.rs, programmer.rs]
2020-07-23 Allow asserting reset before connecting in DAP mode
    [dap.rs]
2020-07-24 Don't force nRESET high when swapping to swd_mode in case it's already been set low
    [gpio.rs]
2020-07-24 Firmware version 1.3.2, fix bug in reset pin handling before connecting
2020-10-12 Add DFU interface to support rebooting into bootloader
    [control_endpoint.rs, descriptors.rs]
